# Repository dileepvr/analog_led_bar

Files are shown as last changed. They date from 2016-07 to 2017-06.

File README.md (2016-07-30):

This PCB schematic and layout is being released under the CERN Open
Hardware License v1.2. All future versions of the CERN Open Hardware
License automatically apply. View the file LICENSE.txt for more
information.

Here is a simple schematic (and BOM) for a circuit that uses 20 leds
(10 for positive and 10 for negative) to indicate the value of an
analog voltage set to a midpoint reference. A potentiometer sets
sensitivity, and an onboard surface mount resistor sets brightness.

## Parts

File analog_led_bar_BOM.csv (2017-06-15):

Part | Qty. | Schematic names | Description | Mouser link:
RK73H2BTTD1001F | 2 | R2, R4 | SM1206 resistors (1K) | http://www.mouser.com/ProductDetail/KOA-Speer/RK73H2BTTD1001F/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
RK73H2BTTD1201F | 2 | R5, R6 | SM1206 resistors (1.2K) | http://www.mouser.com/ProductDetail/KOA-Speer/RK73H2BTTD1201F/
TC33X-2-103E | 1 | RV1 | Trimmer Resistor (10K) | http://www.mouser.com/ProductDetail/Bourns/TC33X-2-103E/
651-0303312 | 2 | P1 | Banana plug receptacles | http://www.mouser.com/ProductDetail/Phoenix-Contact/0303312/
DC10GWA | 1 | BAR1 | 10 LED green array | http://www.mouser.com/ProductDetail/Kingbright/DC10GWA/
DC10SRWA | 1 | BAR2 | 10 LED red array | http://www.mouser.com/ProductDetail/Kingbright/DC10SRWA/
LM3914VX/NOPB | 2 | U2, U3 | TI LED driver ICs (S-PQCC-J20) | http://www.mouser.com/ProductDetail/Texas-Instruments/LM3914VX-NOPB/
TLV8811DBVR | 1 | U1 | SOT-23-5 OpAmp | http://www.mouser.com/ProductDetail/Texas-Instruments/TLV8811DBVR/

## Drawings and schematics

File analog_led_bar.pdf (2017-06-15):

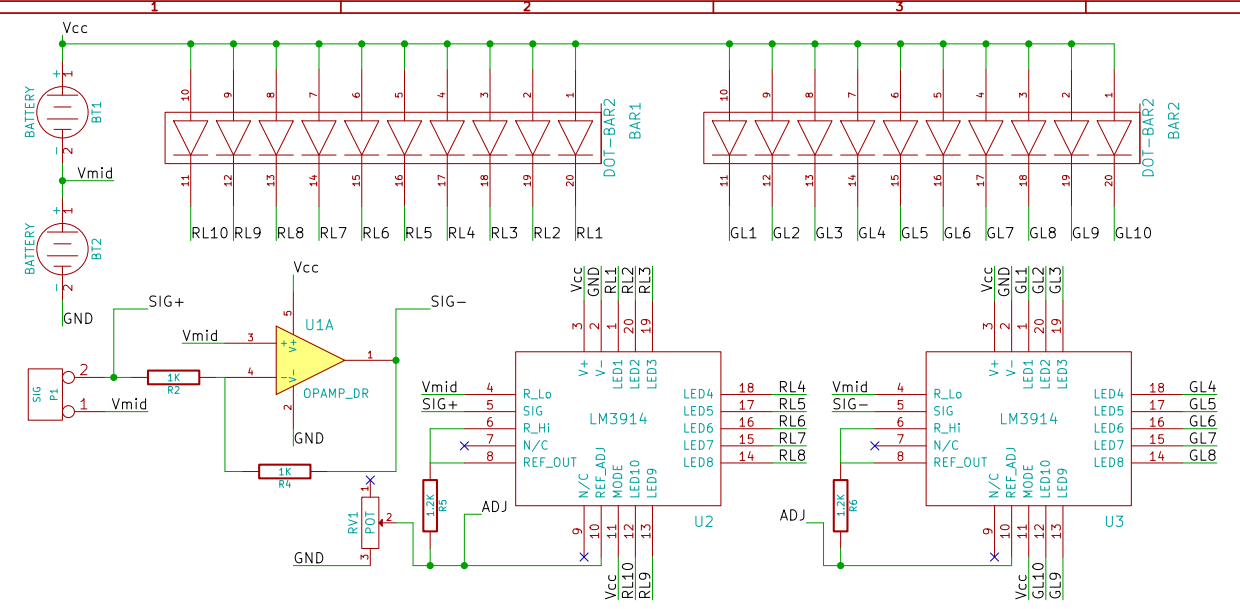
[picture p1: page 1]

Id: 1/1 Title: File: analog_led_bar.sch

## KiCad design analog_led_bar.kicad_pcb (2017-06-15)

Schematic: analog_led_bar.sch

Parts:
BAR1, BAR2: DOT-BAR2
BT1, BT2: BATTERY
P1: SIG
R2, R4: 1K
R5, R6: 1.2K
RV1: POT
U1: OPAMP_DR
U2, U3: LM3914

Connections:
/ADJ: R5.2, R6.2, RV1.2, U2.10 (REF_ADJ), U3.10 (REF_ADJ)
/GL1: BAR2.11 (K), U3.1 (LED1)
/GL2: BAR2.12 (K), U3.20 (LED2)
/GL3: BAR2.13 (K), U3.19 (LED3)
/GL4: BAR2.14 (K), U3.18 (LED4)
/GL5: BAR2.15 (K), U3.17 (LED5)
/GL6: BAR2.16 (K), U3.16 (LED6)
/GL7: BAR2.17 (K), U3.15 (LED7)
/GL8: BAR2.18 (K), U3.14 (LED8)
/GL9: BAR2.19 (K), U3.13 (LED9)
/GL10: BAR2.20 (K), U3.12 (LED10)
/GND: BT2.2 (-), RV1.3, U1.2, U2.2 (V-), U3.2 (V-)
/RL1: BAR1.20 (K), U2.1 (LED1)
/RL2: BAR1.19 (K), U2.20 (LED2)
/RL3: BAR1.18 (K), U2.19 (LED3)
/RL4: BAR1.17 (K), U2.18 (LED4)
/RL5: BAR1.16 (K), U2.17 (LED5)
/RL6: BAR1.15 (K), U2.16 (LED6)
/RL7: BAR1.14 (K), U2.15 (LED7)
/RL8: BAR1.13 (K), U2.14 (LED8)
/RL9: BAR1.12 (K), U2.13 (LED9)
/RL10: BAR1.11 (K), U2.12 (LED10)
/SIG+: P1.2 (PM), R2.2, U2.5 (SIG)
/SIG-: R4.1, U1.1, U3.5 (SIG)
/Vcc: BAR1.1 (A), BAR1.2 (A), BAR1.3 (A), BAR1.4 (A), BAR1.5 (A), BAR1.6 (A), BAR1.7 (A), BAR1.8 (A), BAR1.9 (A), BAR1.10 (A), BAR2.1 (A), BAR2.2 (A), BAR2.3 (A), BAR2.4 (A), BAR2.5 (A), BAR2.6 (A), BAR2.7 (A), BAR2.8 (A), BAR2.9 (A), BAR2.10 (A), BT1.1 (+), U1.5, U2.3 (V+), U2.11 (MODE), U3.3 (V+), U3.11 (MODE)
/Vmid: BT1.2 (-), BT2.1 (+), P1.1, U1.3, U2.4 (R_Lo), U3.4 (R_Lo)
unnamed: R5.1, U2.6 (R_Hi), U2.8 (REF_OUT)
unnamed: R2.1, R4.2, U1.4
unnamed: R6.1, U3.6 (R_Hi), U3.8 (REF_OUT)

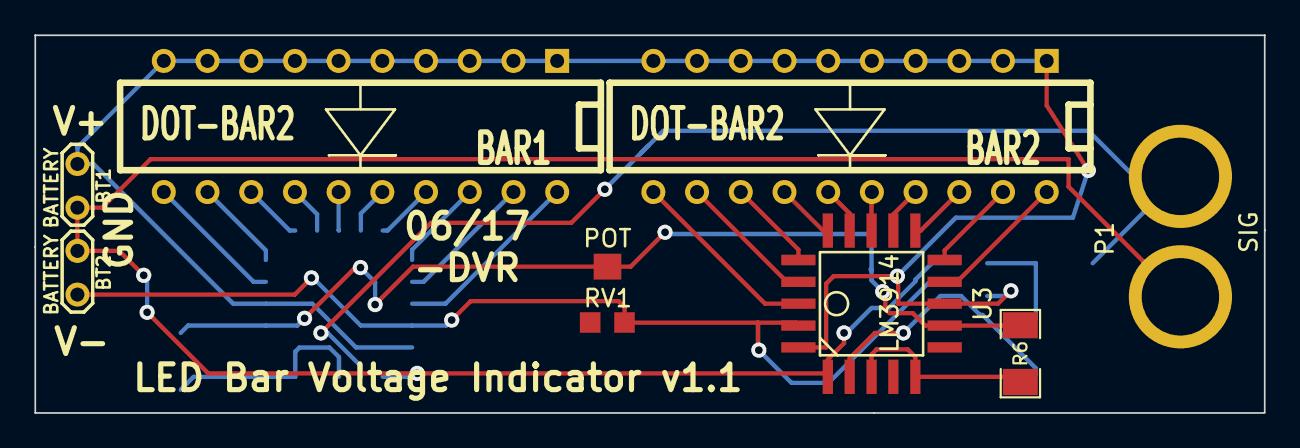
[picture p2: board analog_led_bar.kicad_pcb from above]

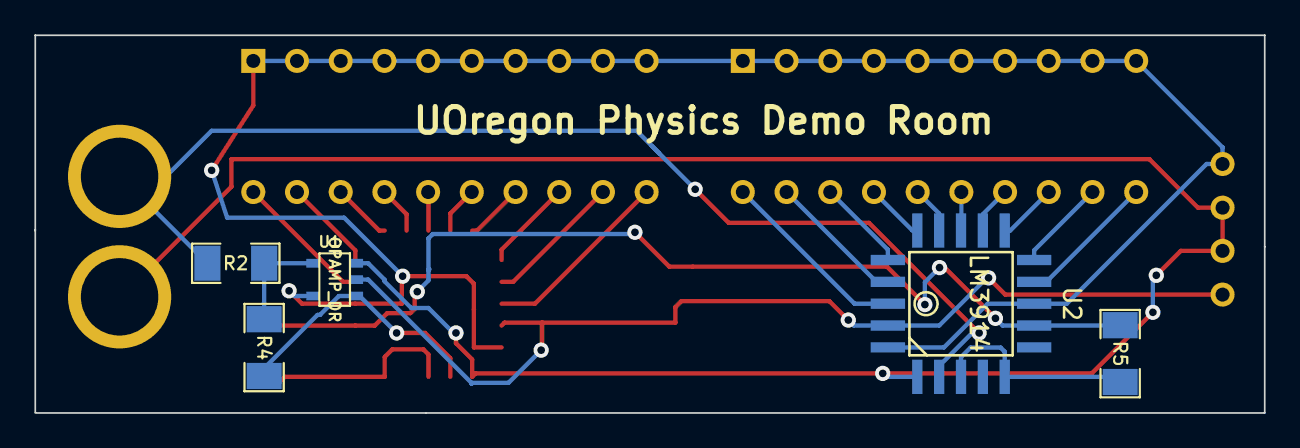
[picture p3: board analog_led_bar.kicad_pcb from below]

Board: 2 copper layers, 71.4 x 22.0 mm, 13 parts (5 on the bottom side), 29 nets.

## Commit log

2016-07-30 Project finished.
    [analog_led_bar-B_Cu.gbl, analog_led_bar-B_Mask.gbs, analog_led_bar-B_Paste.gbp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]
2017-06-15 Fixed unconnected nodes. Now v1.1. Confirmed works if variable resistor is set properly.
    [analog_led_bar-B_Cu.gbl, analog_led_bar-B_Mask.gbs, analog_led_bar-B_Paste.gbp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]
2017-06-15 BOM added.
    [analog_led_bar_BOM.csv]
